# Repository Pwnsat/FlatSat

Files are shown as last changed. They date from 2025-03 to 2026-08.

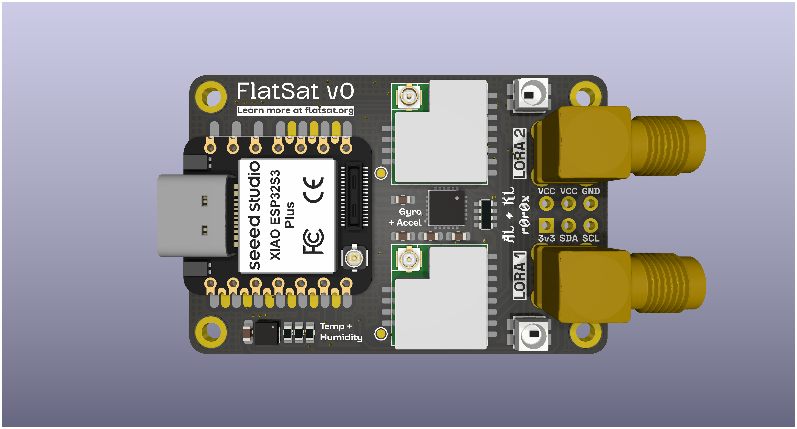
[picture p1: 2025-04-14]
assets/v0_FlatSat-Front.png

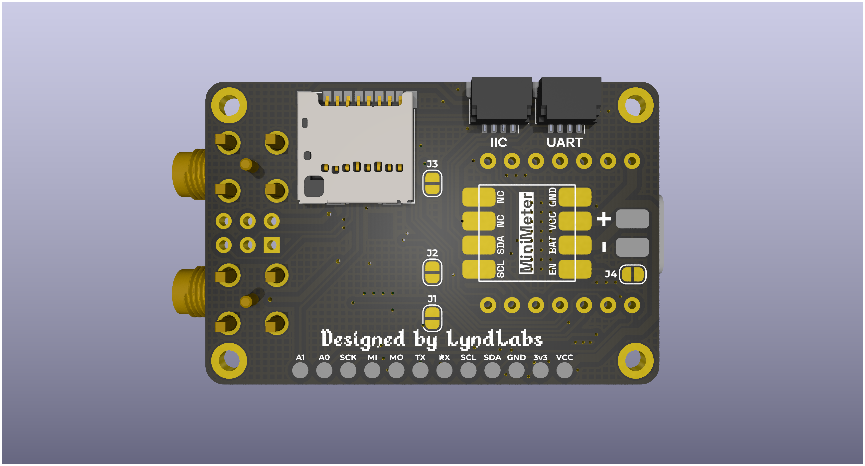
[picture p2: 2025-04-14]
assets/v0_FlatSat-Back.png

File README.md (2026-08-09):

<div align="center">

FlatSat Satellite Security Research Platform Banner

# FlatSat v1.0

**The world’s first open-source and hardware platform vulnerable-by-design, engineered specifically to learn space hacking adn aerospace cybersecurity.**

</div>

---

## Welcome to FlatSat

FlatSat is a hardware-based training platform designed to be vulnerable on purpose. It is built for hackers, engineers, and space enthusiasts who want to dive deep into space-grade systems, learn cybersecurity concepts, and prototype their own payloads in a safe, controlled environment.

The project simulates critical real-world satellite subsystems, orbital telemetry, and authentic aerospace communication protocols, serving as a bridge between hardware hacking and aerospace security research.

---

## What You Can Do With FlatSat

* **Hands-on Learning:** Use FlatSat as the hardware companion to your aerospace cybersecurity studies, featuring lessons on binary exploitation, secure communication, reverse engineering, and space protocols.
* **Hack Real Vulnerabilities:** Explore and exploit firmware designed to simulate historical or realistic software failures in orbiting infrastructure.
* **Join Space CTFs:** Participate in space-themed Capture The Flag challenges that simulate real satellite operation scenarios, turning your board into your own spacecraft.
* **Prototype Your Payloads:** Use the onboard components to develop and test your own payload logic, radio communication, or telemetry systems before deploying larger projects.

---

## Hardware Overview

FlatSat's physical architecture layout is fully accessible and designed for open hardware auditing:

* **On-Board Computer (OBC):** Powered by the dual-core Raspberry Pi RP2040 microcontroller.
* **Dual RF Link Subsystem:** Equipped with two independent Semtech SX1262 sub-GHz LoRa modules dedicated to Uplink (receive) and Downlink (transmit) configurations.
* **Onboard Sensors:** Features a BME280 environmental sensor and a LIS2DH12 3-axis accelerometer to emulate real spatial telemetry.
* **Exposed Auditing Interfaces:** Physical header connector breakouts for direct bus monitoring via UART, I2C, and SWD debug lines.

> **RF Compliance Note:** FlatSat operates exclusively within standard license-free ISM bands (typically 433 MHz or 915 MHz depending on your region). This ensures a legal, safe educational ecosystem that does not interfere with production space systems or critical ground infrastructure.

---

## Firmware & Attacks

* **[`Firmware/`](Firmware/):** The vulnerable-by-design firmware source, a pre-built `.uf2` ready to flash (`Firmware/build/`), and `platformio.ini` to build it yourself. See [`Firmware/README.md`](Firmware/README.md) for the full diff against the public baseline.
* **[`Attacks/`](Attacks/):** Eight attack scripts (`00`–`07`) exploiting the vulnerabilities above, each in an RF variant (HackRF/RTL-SDR) and a USB variant. See [`Attacks/README.md`](Attacks/README.md) for what's here, and the wiki (below) for the full step-by-step walkthrough of each one.

---

## Technical Documentation and Guides (Wiki)

All deep technical documentation, source analysis, and setup guides have been centralized. If you want to start compiling, debugging, or exploiting the platform, please visit the [FlatSat Wiki](https://github.com/Pwnsat/FlatSat/wiki):

* **[01. Quick Start Guide](https://github.com/Pwnsat/FlatSat/wiki/Getting-Started):** Toolchain setup, compiling the firmware, flashing the RP2040, and verifying hardware operations.
* **[02. Hardware Anatomy](https://github.com/Pwnsat/FlatSat/wiki/Hardware-Anatomy-&-Specifications):** Physical layout, schematics, pinouts, and hardware debugging ports.
* **[03. Core Firmware Architecture](https://github.com/Pwnsat/FlatSat/wiki/Firmware-&-System-Architecture):** Deep dive into the Asymmetric Multiprocessing (AMP) architecture dividing tasks across Core 0 and Core 1.
* **[04. Space Packet Protocol (CCSDS)](https://github.com/Pwnsat/FlatSat/wiki/Space-Packet-Protocol---CCSDS):** Aerospace framing standards, packet encapsulation structure, and the active APID registry.
* **[05. Offensive Attack Vectors](https://github.com/Pwnsat/FlatSat/wiki/Satellite-Hacking-&-Attack-Vectors):** The security playground. Explaining packet fuzzing, telecommand spoofing, buffer overflows, and unauthorized subsystem manipulation.
* **[06. Attack Walkthroughs (00–07)](https://github.com/Pwnsat/FlatSat/wiki/Attack-Walkthroughs-00-07):** Step-by-step: prerequisites, the exact command, and how to confirm each of the 8 validated attacks worked against real hardware.

---

## Collaboration and Community

This project is an open-source initiative maintained by PWNSAT and Electronic Cats. Contributions are highly welcome.

## Disclaimer

This project was created for educational purposes, to teach and learn aerospace cybersecurity. Neither PWNSAT nor Electronic Cats are responsible for how the knowledge, code, or tools hosted in this repository are used. Use only against hardware, firmware, or signal sources you own or are explicitly authorized to test.

## License

Electronic Cats invests time and resources providing this open source design, please support Electronic Cats and open-source hardware by purchasing products from Electronic Cats!

Designed by PWNSAT and Electronic Cats.

Hardware released under an CERN Open Hardware Licence v1.2. See the LICENSE_HARDWARE file for more information. Firmware and attack scripts are released under GPL-2.0-or-later — see LICENSE_FIRMWARE and Attacks/LICENSE.

PWNSAT and Electronic Cats are a registered trademark, please do not use if you sell these PCBs.

# Special Thanks
A special thanks to **Alex Lynd**. His support made it possible to kick off the first version of the project, and his contribution remains a fundamental part of PWNSAT. His work will always be embedded in what this project has become.

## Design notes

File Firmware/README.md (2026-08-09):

# Changes vs. the public firmware

**Current version: v1.0.3.** The public v1.0.0 baseline this README diffs
against (previously at the now-retired `Pwnsat/FlatSat_Firmware` repo,
commit `f94aa87`, "FlatSat Firmware v1.0.0 Public") is preserved as a
[legacy v1.0.0 release](https://github.com/Pwnsat/FlatSat/releases/tag/v1.0.0)
on this repo — binary only, since merging its source files alongside this
folder's would just create two conflicting copies of the same file names.

This README documents everything v1.0.3 adds or changes relative to that
v1.0.0 baseline, generated by a direct file-by-file `diff` between both
source trees, not from memory.

## Changelog highlights (v1.0.0 → v1.0.3)

* **New:** ground-station authentication, mission modes, downlink
  encryption (AES-128), GPS navigation, a simulated SpaceCAN bus console,
  a "secured" SPP packet variant, 4 new APIDs — see **New features**
  below for the full breakdown.
* **Fixed:** LoRa radios failing to initialize (missing `tcxoVoltage=0.0`),
  a downlink transmit race, debug-mode payload corruption, 32 misaligned
  serial log lines — see **Bugs fixed** below.
* Every new subsystem above ships with at least one intentional
  vulnerability, backing the [8 attack scripts](../Attacks/) and the
  wiki's [Attack Walkthroughs](https://github.com/Pwnsat/FlatSat/wiki/Attack-Walkthroughs-00-07).

## Summary

The public firmware is a functional baseline: two SX1262 LoRa radios,
CCSDS/SPP protocol, sensors (IMU, BME280), dual-core USB serial console.
This firmware builds on that base and adds **a full layer of simulated
real-satellite-mission subsystems** (ground-station authentication, mission
modes, downlink encryption, a simulated CAN bus, GPS navigation) — with
intentional vulnerabilities, which are what the attack scripts under
[`../Attacks/`](../Attacks/) exploit.

## How to build

**Board:** Raspberry Pi Pico / RP2040 (`#include "hardware/watchdog.h"` is a
Pico SDK header; the sketch uses the RP2040 core from
[earlephilhower](https://github.com/earlephilhower/arduino-pico), which
ships native USB support via `Adafruit_TinyUSB` for this firmware's dual-USB
core).

**Third-party libraries** (Arduino Library Manager, or the PlatformIO
equivalent):

| Library | Used for |
|---|---|
| `RadioLib` | SX1262 LoRa radios (uplink/downlink) |
| `Adafruit_BME280` (pulls in `Adafruit_Sensor` as a transitive dependency) | Environmental sensor |
| `SparkFun_LIS2DH12` | Accelerometer |
| `NeoPixelBus` | Status LED |
| `Adafruit_TinyUSB` (bundled with earlephilhower's RP2040 core, no separate install needed) | Dual-core USB serial console (CDC) |

This folder includes `platformio.ini` (`pico_tinyusb` environment) with all
4 `lib_deps` pinned — `pio run` from here builds with no manual steps. If
you use the Arduino IDE instead, install the earlephilhower RP2040 core via
Boards Manager and the libraries in the table above via Library Manager
before opening `firmware.ino`.

## Pre-built binary

`build/flatsat-firmware.uf2` is a build of this exact source, generated
with the `platformio.ini` above (`pio run`, `pico_tinyusb` environment) —
RAM 8.4% (22016/262144 bytes), Flash 7.8% (163756/2093056 bytes). To flash:
hold the Pico's BOOTSEL button while plugging it in over USB (it enumerates
as a mass-storage volume), then copy the `.uf2` onto it — the Pico reboots
on its own into the new firmware. **Not verified on real hardware:** this
specific binary hasn't been flashed or tested on physical FlatSat hardware
— it's a clean recompile of the source to have a ready artifact, not
necessarily the exact binary that ran during development/testing. The
source code is identical either way; if you need the "ran on real
hardware" guarantee, flash and test this `.uf2` yourself before relying on
it for a live demo.

## New files (don't exist in the public firmware)

| File | What it does |
|---|---|
| `secure_link.cpp` / `.h` | Encrypts/decrypts the downlink payload with AES-128. A static 16-byte key embedded in the binary, ECB mode, no IV — the documented vulnerability. Exposes `secureLinkIsEnabled()`, `secureLinkEncodePayload()`, `secureLinkDecodePayload()`. |
| `spacecan.cpp` / `.h` | Simulated SpaceCAN bus console (serial port, text), with 3 nodes (`SENSOR`/`MOTOR`/`BATTERY`), fragmented-frame reassembly, frame injection with no origin check (`SC INJECT`), and manual node reset (`SC RESET`) — 3 intentional vulnerabilities documented in the file's own header. Also contains the PWNSAT console shell (banner, menu, sensor dashboard mode) — none of this touches the radio/USB command path. |

## Bugs fixed vs. the public firmware

1. **LoRa radios wouldn't initialize (-707 /
   `RADIOLIB_ERR_SPI_CMD_FAILED`) — root cause found and fixed.** The
   public firmware calls `radio0.begin()` / `radio1.begin()` with no
   arguments, which leaves `tcxoVoltage` at RadioLib's default (1.6V) —
   telling the chip to expect a TCXO this module doesn't have (it uses a
   plain XTAL), so internal calibration never completes. Fixed in
   `ruplink.cpp` / `rdownlink.cpp`: explicit `tcxoVoltage=0.0`.
2. **`downlinkRadioTransmit()` (blocking) could fail if a previous
   transmission hadn't finished.** Added `radio1.finishTransmit()` +
   `delay(100)` before transmitting.
3. **`uplinkRadioCheckPacketReceived()` corrupted the received payload in
   debug mode.** The public firmware does a hex-string → bytes → callback
   roundtrip that lost data; raw bytes (`byteArr`) are now passed straight
   to the callback instead.
4. **Misaligned Serial logs.** Several `Serial.printf(...)` calls in
   `ruplink.cpp`/`rdownlink.cpp`/`worker.cpp` ended in `\n` instead of
   `\r\n` — many serial terminals don't return to column 0 without the
   explicit `\r`. 32 occurrences fixed.

## New features

### Ground Station (GS) authentication and access control
A full subsystem in `worker.cpp`: GS modes (`GS_MODE`), access
challenge/response (`GS_ACCESS`), status (`GS_STATUS`). The access "gate"
requires the GPS to report a position within a 35km radius
(`gs_station_radius_m`) of a fixed GS coordinate
(`gs_station_lat_e7`/`gs_station_lon_e7`). The challenge/response uses a
hardcoded shared key (`gs_shared_auth_key = 0xC0DEFACE`) XORed against the
challenge — an intentional vulnerability, exploited by the `05_gs_auth_spoofing`
attack script.

### GPS navigation
`sensors.cpp`/`.h`: a full NMEA parser (GGA/RMC sentences), a new dedicated
UART (`PIN_GPS_TX`/`PIN_GPS_RX`, pins 0/1), a `gps_nav_t` struct with
fix/lat/lon/alt/satellite-count/UTC date-time. A new `GET_NAV` APID
(`0x0E`) exposes a navigation snapshot over telemetry.

### Mission modes
`SAFE` / `NOMINAL` / `PAYLOAD` / `SCIENCE` / `CONTINGENCY` (`mission.h`),
controllable via the new `SET_MISSION_MODE` APID (`0x0D`), with status
flags (`MISSION_FLAG_*`) reporting subsystem health (BME/ACC/GPS/secure
link/payload armed/USB debug active).

### Downlink encryption (secure link)
AES-128 active by default on the downlink payload (`secure_link.cpp`).
Toggled via the `AES_CONFIG` APID (`0x0A`). Static key, no rotation, no IV
— documented as a vulnerability, not an oversight.

### "Secured" SPP packet format (parallel, doesn't replace the existing one)
`spp.cpp`/`.h`: new `spp_tc_build_packet_secured()` /
`spp_tm_build_packet_secured()` functions that prepend a 4-byte secondary
header (a plain monotonic counter, **not cryptographic** — no IV, no
timestamp, no freshness validation) before the payload, setting the
`SecHdr` flag. Doesn't touch any of the 20+ existing callers of
`spp_build_packet()`.

### Other new APIDs
`FLASH_READ` (`0x0B`, reads up to 32 bytes from a fixed blob behind a
hardcoded "unlock tag" `0xC35A` — a flash-read vulnerability with no real
authentication), `GET_STATUS` (`0x0C`), `GET_PAYLOAD_STATUS` (`0x0F`),
`DEBUG_CONFIG` (`0x10`, enables debug commands over USB only).

### Command source separation (radio vs. USB)
The public firmware had a single `commandHandler()`. There are now
`commandHandlerRadio()` / `commandHandlerUSB()`, both reaching
`commandHandlerInternal(..., command_source_t source)` — this lets certain
commands (debug, some GS commands) be restricted to a specific origin
(`groundStationCommandAllowed()`, `source == COMMAND_SOURCE_USB` checks).

### Serial-console telemetry dashboard
`printSystemStatusDashboard()` / `telemetryDashboardWorker()` — an
interactive text mode that shows live sensor/GPS/GS/mission state,
launched from the PWNSAT console (`spacecan.cpp`), without affecting the
radio loop.

## Cross-reference with the vulnerability catalog

This firmware is the base the [`../Attacks/`](../Attacks/) scripts (00–07)
are built against, and covers 11 findings from the internal vulnerability
catalog (#4, #5, #10, #12, #13, #14, #15, #16, #17, #21, #22). See
[`../Attacks/README.md`](../Attacks/README.md) and the wiki for the
per-attack detail.

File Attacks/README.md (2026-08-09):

# FlatSat Attacks 00–07

Eight attack scripts exploiting the vulnerabilities documented in
[`../Firmware/`](../Firmware/), each available in two variants:

- **`*_rf.py`** — the physically-realistic version, over the air via
  HackRF (uplink) and RTL-SDR/CatSniffer (downlink). Confirmed on real
  hardware.
- **`*_usb.py`** — the same finding, delivered over FlatSat's USB serial
  link instead of RF. Useful to rehearse the effect without an SDR.

| Folder | Attack | APID(s) |
| --- | --- | --- |
| `00_recon_apid_enum/` | Unauthenticated black-box APID enumeration | various |
| `01_eavesdropping/` | Passive downlink decryption (static AES-128 key) | `SEND_TM` |
| `02_fuzzing_crash/` | `BROADCAST_MSG` integer underflow crash | `0x06` |
| `03_command_injection/` | Unauthenticated `SET_THRUSTER` | `0x04` |
| `04_gps_spoofing/` | Real GPS L1 spoofing + a debug GPS-override demo | — |
| `05_gs_auth_spoofing/` | Ground-station auth bypass (static XOR key) | `0x12` |
| `06_replay/` | Telecommand replay (no anti-replay) | `0x01` |
| `07_resetc/` | Unauthenticated `RESETC` reboot | `0x02` |

Full step-by-step walkthrough for each attack — prerequisites, exact
commands, and how to confirm it worked — is in the wiki:
**[Attack Walkthroughs (00–07)](https://github.com/Pwnsat/FlatSat/wiki/Attack-Walkthroughs-00-07)**.
This README only lists what's here; it isn't a substitute for that page.

## Dependency: PWNSAT-C3

None of these scripts vendor their own SPP/CCSDS codec or AES
implementation — `lib/pwnsat_packets.py` and `lib/flatsat_usb.py` import
`pwnsat_tools/` from **[PWNSAT-C3](https://github.com/Pwnsat/PWNSAT-C3)**,
the ground-station dashboard repo. Clone both repos as siblings under the
same parent directory:

```shell
git clone https://github.com/Pwnsat/FlatSat
git clone https://github.com/Pwnsat/PWNSAT-C3
```

```
some-parent-dir/
├── FlatSat/
│   └── Attacks/   <- you are here
└── PWNSAT-C3/
    └── pwnsat_tools/
```

No other install step is needed beyond what
[PWNSAT-C3's own INSTALL.md](https://github.com/Pwnsat/PWNSAT-C3/wiki/Getting-Started)
already covers (Python deps, and the optional GNU Radio/SoapySDR/HackRF
toolchain the `_rf.py` scripts need).

## `lib/`

Shared code the scripts above import, not run directly:

| File | Purpose |
| --- | --- |
| `pwnsat_packets.py` | Bootstraps `pwnsat_tools/` onto `sys.path` and re-exports packet building/decoding. |
| `flatsat_usb.py` | `FlatSatUSB` — the USB serial transport the `*_usb.py` scripts use. |
| `pwnsat_lora_tx.py` | HackRF TX helper (shells out to `hackrf_transfer`). |
| `pwnsat_lora_rx_capture.py` | GNU Radio LoRa RX capture helper. |
| `pwnsat_catsniffer_rx.py` | CatSniffer-based dedicated downlink listener (two-radio setup). |
| `pwnsat_rtlsdr_rx.py` | RTL-SDR downlink listener, reuses `01_eavesdropping/pwnsat_lora_rx.py`. |
| `decrypt_display.py` | Decrypts and pretty-prints a captured downlink payload. |
| `require_gnuradio.py` | Fails fast with a clear message if GNU Radio isn't importable. |

## Safety

Every script here transmits over RF or sends real commands. Only run these
against a FlatSat board, lab transmitter, or signal source you own or are
explicitly authorized to test.

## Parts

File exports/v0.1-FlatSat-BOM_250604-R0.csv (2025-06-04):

Designator | Value | Footprint | Datasheet | LCSC | Qty
C1,C3,C4,C5,C6 | 100nF | 603 | ~ | C14663 | 5
C2 | 2.2uf | 603 | ~ | C57895 | 1
D1,D2 | SK6812MINI | 3535 |  | C2922787 | 2
J2,J3 | JST SH | SM04B | ~ | C160404 | 2
J7 | MicroSD |  | https://www.molex.com/en-us/products/part-detail/1040310811 | C585350 | 1
R4,R5 | 4.7K | 603 | ~ | C99782 | 2
RN1 | 10K | Resistor_SMD:R_Array_Convex_4x0603 | ~ | C110924 | 1
U2 | MPU-6500 | Sensor_Motion:InvenSense_QFN-24_4x4mm_P0.5mm | https://invensense.tdk.com/wp-content/uploads/2015/02/MPU-6000-Datasheet1.pdf | C50278 | 1
U3 | BME280 | Package_LGA:Bosch_LGA-8_2.5x2.5mm_P0.65mm_ClockwisePinNumbering | https://www.bosch-sensortec.com/media/boschsensortec/downloads/datasheets/bst-bme280-ds002.pdf | C92489 | 1
U5,U6 | WIO-SX1262 |  | https://www.seeedstudio.com/Wio-SX1262-Wireless-Module-p-5981.html | NA | 2

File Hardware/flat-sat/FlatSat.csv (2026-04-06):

Reference | Value | Footprint | Qty | LCSC# | Mouser# | manf# | DNP
BOOT1,Button1,Button2,RESET1 | SW | FlatSat:TS1088R02026 | 4 | C455281
C1,C5,C7,C8,C13,C14,C18,C19,C24,C25,C27,C28,C32,C33,C34,C35,C36,C37,C38 | 0.1uF | Capacitor_SMD:C_0402_1005Metric | 19 | C56392
C2,C15 | 100pF | Capacitor_SMD:C_0402_1005Metric | 2 | C541374
C3,C4,C16,C17 | 3.3pF | Capacitor_SMD:C_0402_1005Metric | 4 | C1565
C6,C26,C31 | 1uF | Capacitor_SMD:C_0402_1005Metric | 3 | C52923
C9,C20 | 47pF | Capacitor_SMD:C_0402_1005Metric | 2 | C437519
C10,C12,C21,C23 | 1nF | Capacitor_SMD:C_0402_1005Metric | 4 | C335530
C11,C22 | 470nF | Capacitor_SMD:C_0402_1005Metric | 2 | C47339
C29,C30 | 27pF | Capacitor_SMD:C_0402_1005Metric | 2 | C424826 | 81-GJM1555C1H270FB1D
D2 | SK6812MINI | Library:SK6812MINI-HS | 1 | C2922787
F1 | 0.75A | Fuse:Fuse_0603_1608Metric_Pad1.05x0.95mm_HandSolder | 1 | C182438 | 594-MFU0805FF00500P1
J1,J2 | Antenna | FlatSat:SMA_EDGE | 2 | C530661
J3 | periphs | Connector_PinHeader_2.54mm:PinHeader_1x06_P2.54mm_Vertical | 1
J4 | SWD | Connector_PinHeader_2.54mm:PinHeader_1x04_P2.54mm_Vertical | 1 |  |  |  | DNP
JP1,JP2 | Jumper | Jumper:SolderJumper-3_P1.3mm_Bridged12_RoundedPad1.0x1.5mm_NumberLabels | 2 |  |  |  | DNP
L1,L4 | 9.1nH | Inductor_SMD:L_0603_1608Metric | 2 | C395094
L2,L5 | 47nH | Inductor_SMD:L_0603_1608Metric | 2 | C578001
L3,L6 | 15uH | Inductor_SMD:L_0603_1608Metric | 2 | C57838
P1 | USB_C_Plug_USB2.0 | FlatSat:C393939 | 1 | C709357
R1,R2 | 5k1 | Resistor_SMD:R_0402_1005Metric | 2 | C25905
R3,R4,R6,R7 | 100R | Resistor_SMD:R_0402_1005Metric | 4 | C25076
R5 | 10k | Resistor_SMD:R_0402_1005Metric | 1 | C25531 | 594-MCS04020D1002BE0
R8,R10 | 27 | Resistor_SMD:R_0402_1005Metric | 2 | C25100 | 755-ESR01MZPF27R0
R9,R15 | 4.7k | Resistor_SMD:R_0402_1005Metric | 2 | C25900 | 594-MCS04020D1002BE0
R13 | 1k | Resistor_SMD:R_0402_1005Metric | 1 | C11702 | 594-MCS0402MD1001DE0
R14 | 470 | Resistor_SMD:R_0402_1005Metric | 1 | C25117
U1 | TLV75733PDBVR | Package_TO_SOT_SMD:SOT-23-5 | 1 | C485517
U2,U6 | 0900FM15D0039 | FlatSat:0900FM15D0039E | 2 |  | 609-0900FM15D0039E | 0900FM15D0039E
U3,U7 | PE42421 | Package_TO_SOT_SMD:SOT-363_SC-70-6 | 2 | C470893 | 81-PE42421SCAA-Z | PE42421SCAA-Z
U4,U8 | SX1262IMLTRT | Package_DFN_QFN:QFN-24-1EP_4x4mm_P0.5mm_EP2.65x2.65mm | 2 | C191341 | 947-SX1262IMLTRT | SX1262IMLTRT
U5 | IS25LP032D-JTLE-TR | Package_SON:Winbond_USON-8-2EP_3x4mm_P0.8mm_EP0.2x0.8mm | 1 | C5119926 |  | IS25LP032D-JTLE-TR
U9 | RP2040 | Package_DFN_QFN:QFN-56-1EP_7x7mm_P0.4mm_EP3.2x3.2mm | 1 | C2040 |  | RP2040
U10 | LIS2DH | Package_LGA:LGA-14_2x2mm_P0.35mm_LayoutBorder3x4y | 1 | C155670
U11 | BME280 /BMP280 | Package_LGA:Bosch_LGA-8_2.5x2.5mm_P0.65mm_ClockwisePinNumbering | 1 | C92489
Y1,Y2 | 32Mhz | Crystal:Crystal_SMD_2520-4Pin_2.5x2.0mm | 2 | C255969 |  | Q24FA20H0021700
Y3 | 12MHz | Crystal:Crystal_SMD_3225-4Pin_3.2x2.5mm | 1 | C2848217 |  | XC32M4-12.000-F20NJDT

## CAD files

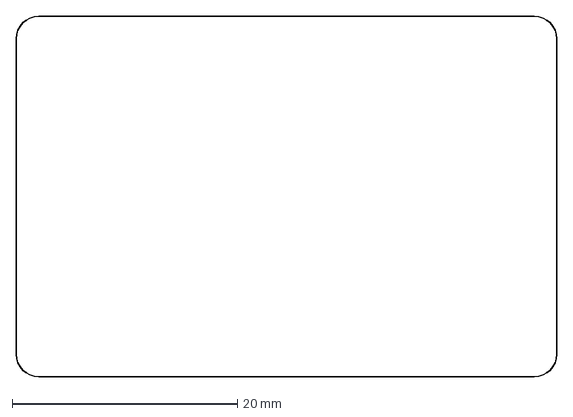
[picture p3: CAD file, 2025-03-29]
assets/outline.dxf
48.0 x 32.0 mm

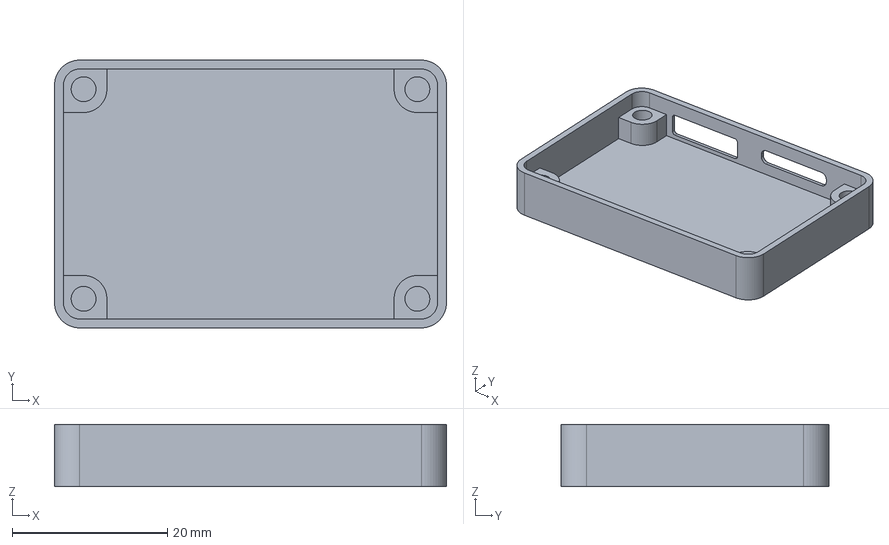
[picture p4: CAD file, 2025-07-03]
exports/v0-FlatSat-Enclosure.step
50.5 x 34.5 x 8.00 mm

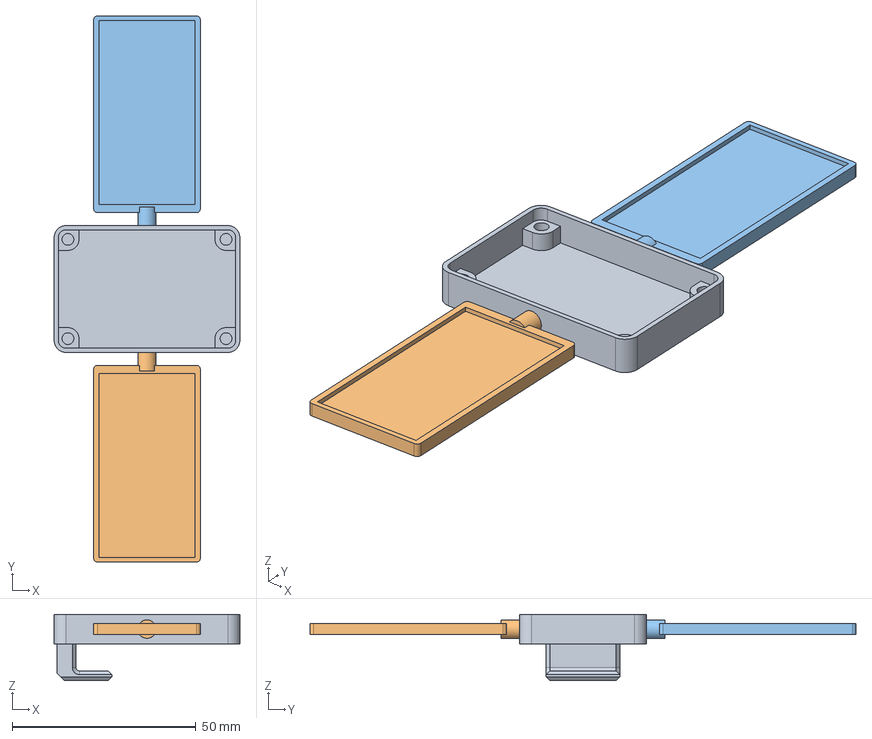
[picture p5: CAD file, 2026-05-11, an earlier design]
Hardware/Legacy/v0-FlatSat-Sat_MOunt.FCStd
50.5 x 148.5 x 18.0 mm
SolarPanel2
SolarPanel1

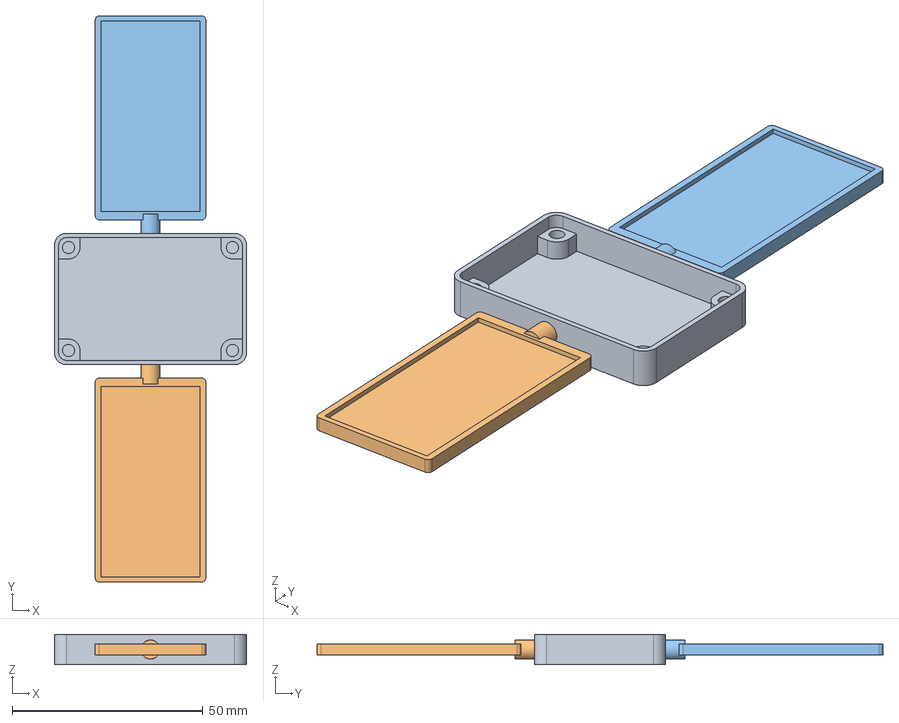
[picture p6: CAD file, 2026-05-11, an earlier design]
Hardware/Legacy/v0-FlatSat-Sat.FCStd
50.5 x 148.5 x 8.00 mm
SolarPanel2
SolarPanel1

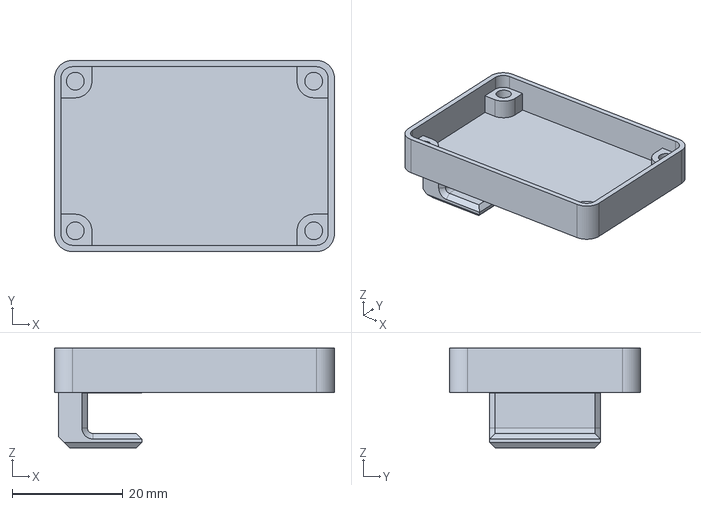
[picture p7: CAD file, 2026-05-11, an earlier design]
Hardware/Legacy/v0-FlatSat-Mount.FCStd
50.5 x 34.5 x 18.0 mm

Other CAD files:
src/v0-FlatSat-Enclosure.FCStd
Hardware/Legacy/v0-FlatSat-Outline.FCStd
Hardware/Legacy/v0-FlatSat-Sat-SolarPanel.step
Hardware/Legacy/v0-FlatSat-Enclosure-Body_STL.stl
Hardware/Legacy/v0-FlatSat-Enclosure.FCStd
Hardware/Legacy/v0-FlatSat-Sat-Mount.stl
Hardware/Legacy/v0-FlatSat-Sat-SolarPanel.stl

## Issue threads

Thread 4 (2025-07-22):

v1.0 - RFM95

JahazielLem, 2025-07-22:
- Make board easily compatible with RFM95 as new version radio

JahazielLem, 2025-07-22:
Or LR1121, maybe a modern o more complex version
https://www.seeedstudio.com/Wio-LR1121-with-IPEX-antenna-connector-p-6479.html

AlexLynd, 2025-07-24:
Working on it now!  Just need to route the traces...

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

AlexLynd, 2025-07-26:
How many more pins do we need?  On the last version, we had 2 unused pins - and I think we'll have the same on this one.  And also, do we intend to sell this as a "workshop edition" or just for presenters?  I can definitely get us a discount / sponsored parts!

JahazielLem, 2025-07-29:
With the two free is enough, with the LR1121 is only for presenters but with the sx1262 or RFM is for sell, so here we can look for sponsorship o collabs

AlexLynd, 2025-08-05:
Got it!  Also should I also get rid of microsd detection pin?  I feel like we can just detect it in software... and there's not really a reason to have detection tied to an interrupt

AlexLynd, 2025-08-05:
@JahazielLem also you want `DIO9` connected on just one of them?  what about the busy pins
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

JahazielLem, 2025-08-06:
@AlexLynd  I will bought a module, in the next week will arrive, so let me test what's the better configuration for the pins, maybe the board with this module will have only one LR11 and a RFM as the second radio

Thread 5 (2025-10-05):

Inquiry about purchasing FlatSat kit

hadi1123, 2025-10-05:
Hello! 👋
I came across your FlatSat project and I’m really interested in purchasing one for educational and research purposes. However, I couldn’t find a purchasing link or store page in the repository.

Could you please share details about how or where I can buy the FlatSat kit (or any recommended distributor)?

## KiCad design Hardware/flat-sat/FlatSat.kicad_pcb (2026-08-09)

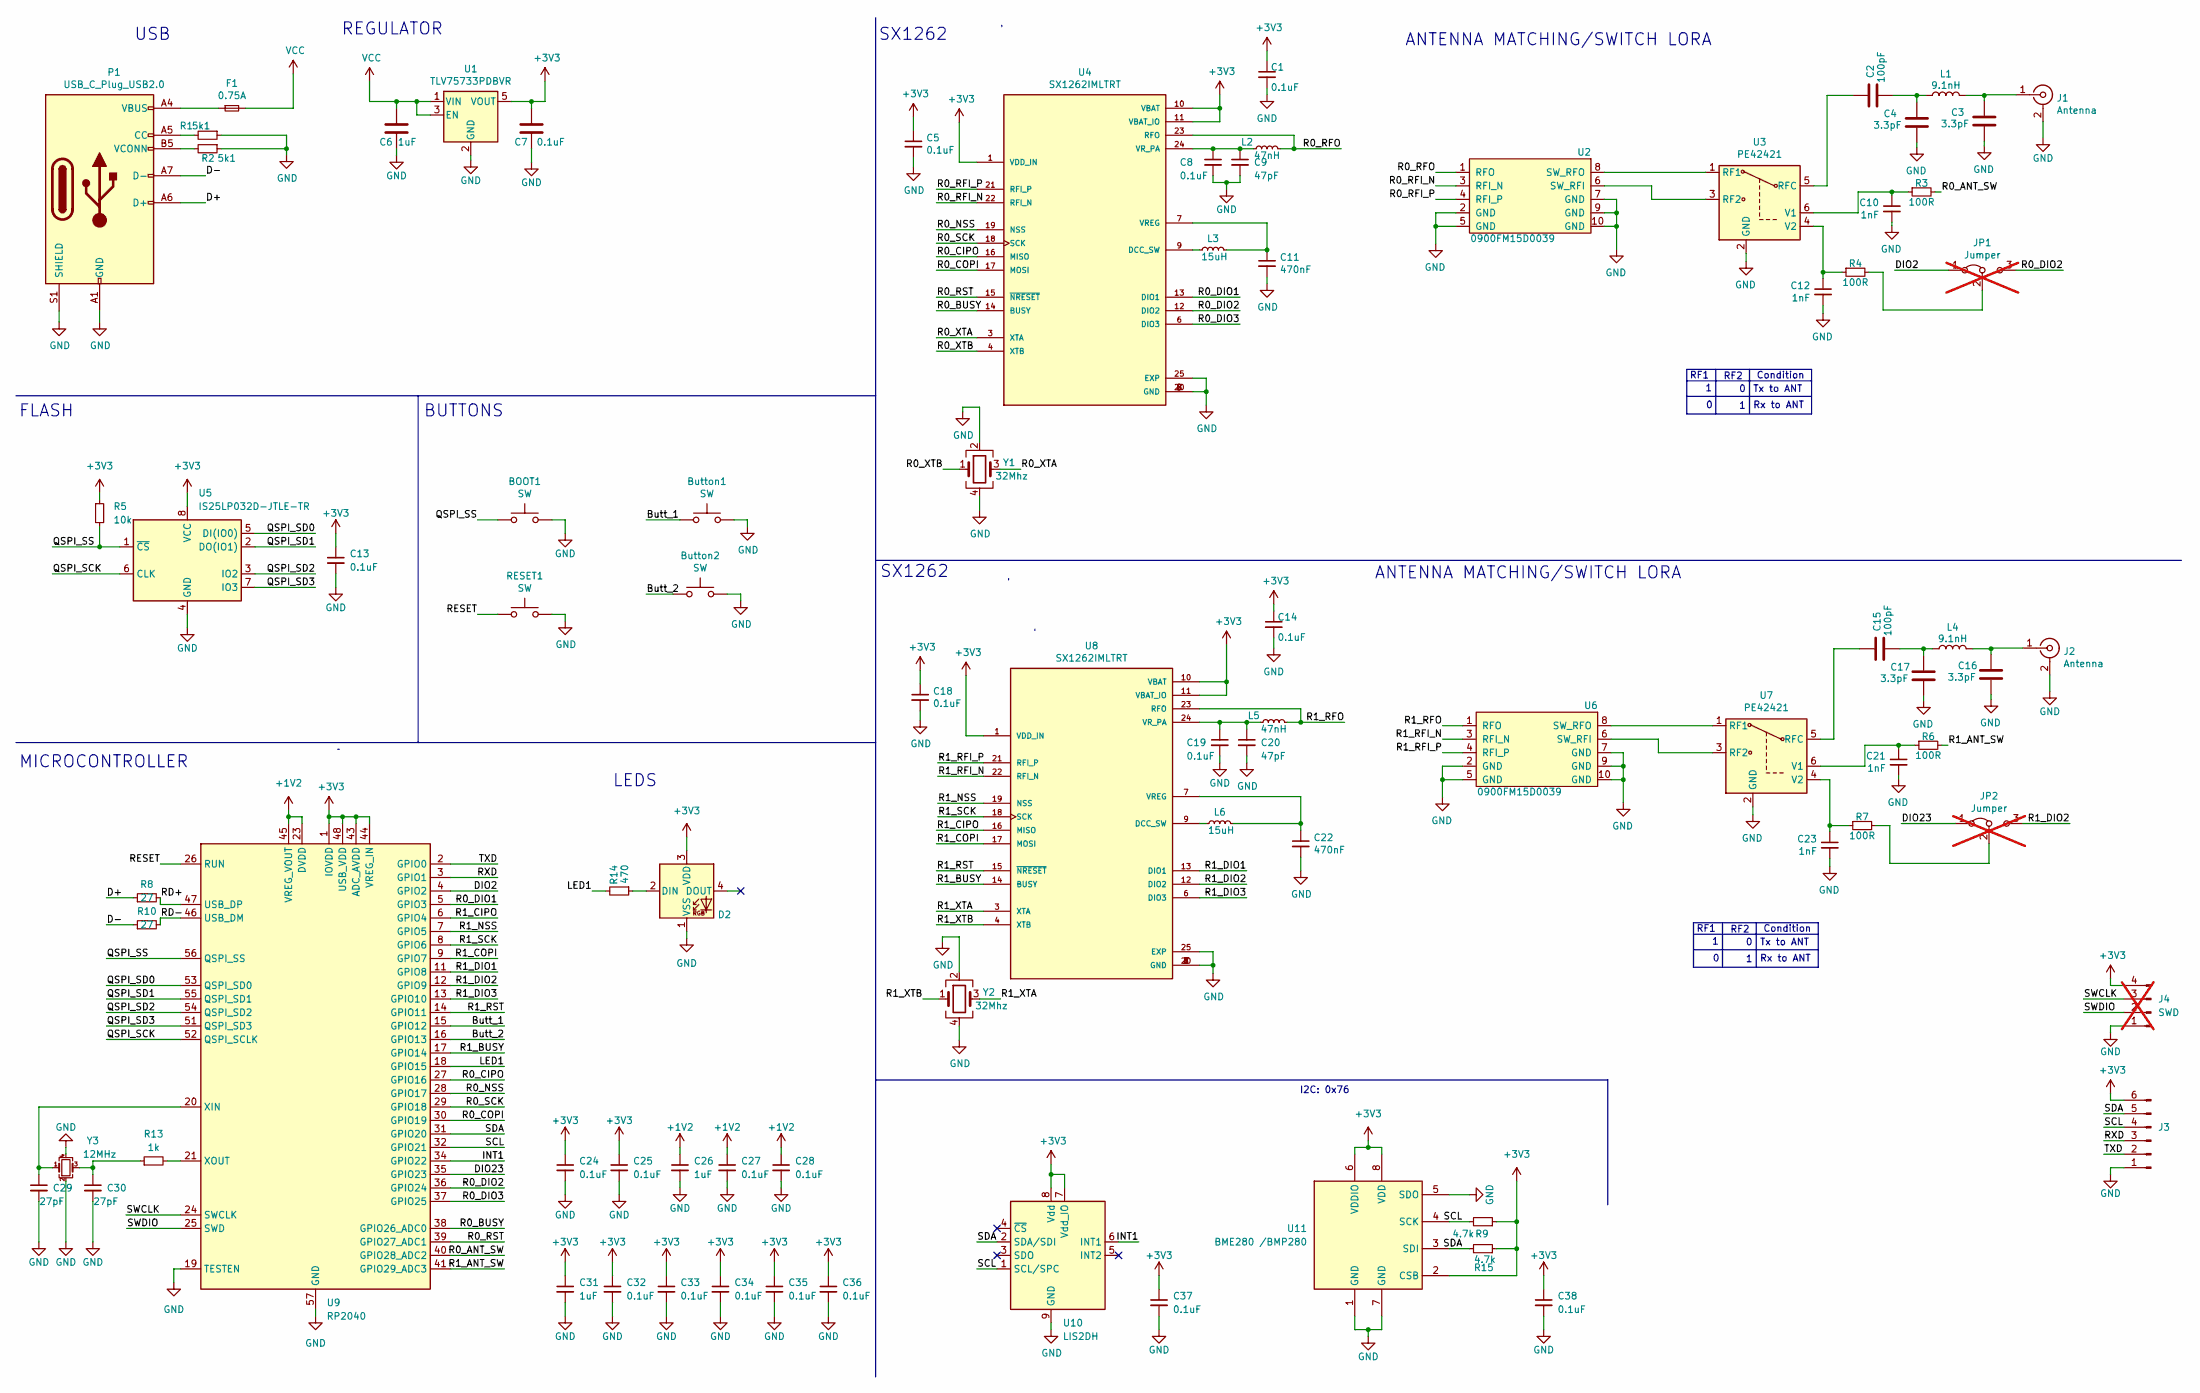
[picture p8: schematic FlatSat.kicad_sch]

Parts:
BOOT1: SW; TS1088R02026; LCSC# C455281
Button1, Button2: SW; TS1088R02026; LCSC# C455281
C1, C5, C7, C8, C13, C14, C18, C19, C24, C25, C27, C28, C32, C33, C34, C35, C36, C37, C38: 0.1uF; C_0402_1005Metric; LCSC# C56392
C2, C15: 100pF; C_0402_1005Metric; LCSC# C541374
C3, C4, C16, C17: 3.3pF; C_0402_1005Metric; LCSC# C1565
C6, C26, C31: 1uF; C_0402_1005Metric; LCSC# C52923
C9, C20: 47pF; C_0402_1005Metric; LCSC# C437519
C10, C12, C21, C23: 1nF; C_0402_1005Metric; LCSC# C335530
C11, C22: 470nF; C_0402_1005Metric; LCSC# C47339
C29, C30: 27pF; C_0402_1005Metric; Mouser# 81-GJM1555C1H270FB1D; LCSC# C424826
D2: SK6812MINI; SK6812MINI-HS; LCSC# C2922787
F1: 0.75A; Fuse_0603_1608Metric_Pad1.05x0.95mm_HandSolder; Mouser# 594-MFU0805FF00500P1
J1, J2: Antenna; SMA_EDGE; LCSC# C530661
J3: periphs; PinHeader_1x06_P2.54mm_Vertical
J4: SWD; PinHeader_1x04_P2.54mm_Vertical; not fitted
JP1, JP2: Jumper; SolderJumper-3_P1.3mm_Bridged12_RoundedPad1.0x1.5mm_NumberL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; not fitted
L1, L4: 9.1nH; L_0603_1608Metric; LCSC# C395094
L2, L5: 47nH; L_0603_1608Metric; LCSC# C578001
L3, L6: 15uH; L_0603_1608Metric; LCSC# C57838
P1: USB_C_Plug_USB2.0; C393939; LCSC# C709357
R1, R2: 5k1; R_0402_1005Metric; LCSC# C25905
R3, R4, R6, R7: 100R; R_0402_1005Metric; LCSC# C25076
R5: 10k; R_0402_1005Metric; Mouser# 594-MCS04020D1002BE0; LCSC# C25531
R8, R10: 27; R_0402_1005Metric; Mouser# 755-ESR01MZPF27R0; LCSC# C25100
R9, R15: 4.7k; R_0402_1005Metric; Mouser# 594-MCS04020D1002BE0; LCSC# C25900
R13: 1k; R_0402_1005Metric; Mouser# 594-MCS0402MD1001DE0; LCSC# C11702
R14: 470; R_0402_1005Metric; LCSC# C25117
RESET1: SW; TS1088R02026; LCSC# C455281
U1: TLV75733PDBVR; SOT-23-5; LCSC# C485517
U2, U6: 0900FM15D0039; 0900FM15D0039E; Mouser# 609-0900FM15D0039E
U3, U7: PE42421; SOT-363_SC-70-6; Mouser# 81-PE42421SCAA-Z; LCSC# C470893
U4, U8: SX1262IMLTRT; QFN-24-1EP_4x4mm_P0.5mm_EP2.65x2.65mm; Mouser# 947-SX1262IMLTRT
U5: IS25LP032D-JTLE-TR; Winbond_USON-8-2EP_3x4mm_P0.8mm_EP0.2x0.8mm; LCSC# C5119926
U9: RP2040; QFN-56-1EP_7x7mm_P0.4mm_EP3.2x3.2mm; LCSC# C2040
U10: LIS2DH; LGA-14_2x2mm_P0.35mm_LayoutBorder3x4y; LCSC# C155670
U11: BME280 /BMP280; Bosch_LGA-8_2.5x2.5mm_P0.65mm_ClockwisePinNumbering; LCSC# C92489
Y1, Y2: 32Mhz; Crystal_SMD_2520-4Pin_2.5x2.0mm; LCSC# C255969
Y3: 12MHz; Crystal_SMD_3225-4Pin_3.2x2.5mm; LCSC# C2848217

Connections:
+1V2: C26.1, C27.1, C28.1, U9.23 (DVDD), U9.45 (VREG_VOUT), U9.50 (DVDD)
+3V3: C1.1, C5.1, C7.2, C13.1, C14.1, C18.1, C24.1, C25.1, C31.1, C32.1, C33.1, C34.1, C35.1, C36.1, C37.1, C38.1, D2.3 (VDD), J3.6, J4.4, R5.1, R9.1, R15.1, U1.5 (VOUT), U4.1 (VDD_IN), U4.10 (VBAT), U4.11 (VBAT_IO), U5.8 (VCC), U8.1 (VDD_IN), U8.10 (VBAT), U8.11 (VBAT_IO), U9.1 (IOVDD), U9.10 (IOVDD), U9.22 (IOVDD), U9.33 (IOVDD), U9.42 (IOVDD), U9.43 (ADC_AVDD), U9.44 (VREG_IN), U9.48 (USB_VDD), U9.49 (IOVDD), U10.7 (Vdd_IO), U10.8 (Vdd), U11.2 (CSB), U11.6 (VDDIO), U11.8 (VDD)
/Butt_1: Button1.1, U9.15 (GPIO12)
/Butt_2: Button2.1, U9.16 (GPIO13)
/D+: P1.A6 (D+), R8.1
/D-: P1.A7 (D-), R10.1
/DIO2: JP1.1 (A), U9.4 (GPIO2)
/DIO23: JP2.1 (A), U9.35 (GPIO23)
/INT1: U9.34 (GPIO22), U10.6 (INT1)
/LED1: R14.2, U9.18 (GPIO15)
/QSPI_SCK: U5.6 (CLK), U9.52 (QSPI_SCLK)
/QSPI_SD0: U5.5 (DI(IO0)), U9.53 (QSPI_SD0)
/QSPI_SD1: U5.2 (DO(IO1)), U9.55 (QSPI_SD1)
/QSPI_SD2: U5.3 (IO2), U9.54 (QSPI_SD2)
/QSPI_SD3: U5.7 (IO3), U9.51 (QSPI_SD3)
/QSPI_SS: BOOT1.1, R5.2, U5.1 (~CS), U9.56 (QSPI_SS)
/R0_ANT_SW: R3.2, U9.40 (GPIO28_ADC2)
/R0_BUSY: U4.14 (BUSY), U9.38 (GPIO26_ADC0)
/R0_CIPO: U4.16 (MISO), U9.27 (GPIO16)
/R0_COPI: U4.17 (MOSI), U9.30 (GPIO19)
/R0_DIO1: U4.13 (DIO1), U9.5 (GPIO3)
/R0_DIO2: JP1.3 (B), U4.12 (DIO2), U9.36 (GPIO24)
/R0_DIO3: U4.6 (DIO3), U9.37 (GPIO25)
/R0_NSS: U4.19 (NSS), U9.28 (GPIO17)
/R0_RFI_N: U2.3 (RFI_N), U4.22 (RFI_N)
/R0_RFI_P: U2.4 (RFI_P), U4.21 (RFI_P)
/R0_RFO: L2.2, U2.1 (RFO), U4.23 (RFO)
/R0_RST: U4.15 (~NRESET), U9.39 (GPIO27_ADC1)
/R0_SCK: U4.18 (SCK), U9.29 (GPIO18)
/R0_XTA: U4.3 (XTA), Y1.3
/R0_XTB: U4.4 (XTB), Y1.1
/R1_ANT_SW: R6.2, U9.41 (GPIO29_ADC3)
/R1_BUSY: U8.14 (BUSY), U9.17 (GPIO14)
/R1_CIPO: U8.16 (MISO), U9.6 (GPIO4)
/R1_COPI: U8.17 (MOSI), U9.9 (GPIO7)
/R1_DIO1: U8.13 (DIO1), U9.11 (GPIO8)
/R1_DIO2: JP2.3 (B), U8.12 (DIO2), U9.12 (GPIO9)
/R1_DIO3: U8.6 (DIO3), U9.13 (GPIO10)
/R1_NSS: U8.19 (NSS), U9.7 (GPIO5)
/R1_RFI_N: U6.3 (RFI_N), U8.22 (RFI_N)
/R1_RFI_P: U6.4 (RFI_P), U8.21 (RFI_P)
/R1_RFO: L5.2, U6.1 (RFO), U8.23 (RFO)
/R1_RST: U8.15 (~NRESET), U9.14 (GPIO11)
/R1_SCK: U8.18 (SCK), U9.8 (GPIO6)
/R1_XTA: U8.3 (XTA), Y2.3
/R1_XTB: U8.4 (XTB), Y2.1
/RD+: R8.2, U9.47 (USB_DP)
/RD-: R10.2, U9.46 (USB_DM)
/RESET: RESET1.1, U9.26 (RUN)
/RXD: J3.3, U9.3 (GPIO1)
/SCL: J3.4, R9.2, U9.32 (GPIO21), U10.1 (SCL/SPC), U11.4 (SCK)
/SDA: J3.5, R15.2, U9.31 (GPIO20), U10.2 (SDA/SDI), U11.3 (SDI)
/SWCLK: J4.3, U9.24 (SWCLK)
/SWDIO: J4.2, U9.25 (SWD)
/TXD: J3.2, U9.2 (GPIO0)
GND: BOOT1.2, Button1.2, Button2.2, C1.2, C3.2, C4.2, C5.2, C6.1, C7.1, C8.2, C9.2, C10.2, C11.2, C12.2, C13.2, C14.2, C16.2, C17.2, C18.2, C19.2, C20.2, C21.2, C22.2, C23.2, C24.2, C25.2, C26.2, C27.2, C28.2, C29.2, C30.2, C31.2, C32.2, C33.2, C34.2, C35.2, C36.2, C37.2, C38.2, D2.1 (VSS), J1.2 (Ext), J2.2 (Ext), J3.1, J4.1, P1.A1 (GND), P1.A12 (GND), P1.B1 (GND), P1.B12 (GND), P1.S1 (SHIELD), R1.1, R2.1, RESET1.2, U1.2 (GND), U2.2 (GND), U2.5 (GND), U2.7 (GND), U2.9 (GND), U2.10 (GND), U3.2 (GND), U4.2 (GND), U4.5 (GND), U4.8 (GND), U4.20 (GND), U4.25 (EXP), U5.4 (GND), U6.2 (GND), U6.5 (GND), U6.7 (GND), U6.9 (GND), U6.10 (GND), U7.2 (GND), U8.2 (GND), U8.5 (GND), U8.8 (GND), U8.20 (GND), U8.25 (EXP), U9.19 (TESTEN), U9.57 (GND), U10.9 (GND), U10.10 (GND), U10.11 (GND), U10.12 (GND), U10.13 (GND), U10.14 (GND), U11.1 (GND), U11.5 (SDO), U11.7 (GND), Y1.2, Y1.4, Y2.2, Y2.4, Y3.2, Y3.4
unnamed: C2.2, C4.1, L1.2
unnamed: C15.2, C17.1, L4.2
unnamed: C30.1, R13.1, Y3.3
unnamed: D2.2 (DIN), R14.1
unnamed: F1.1, P1.A4 (VBUS), P1.A9 (VBUS), P1.B4 (VBUS), P1.B9 (VBUS)
unnamed: C3.1, J1.1 (In), L1.1
unnamed: C16.1, J2.1 (In), L4.1
unnamed: JP1.2 (C), R4.2
unnamed: JP2.2 (C), R7.2
unnamed: P1.A5 (CC), R1.2
unnamed: P1.B5 (VCONN), R2.2
unnamed: U2.6 (SW_RFI), U3.3 (RF2)
unnamed: U2.8 (SW_RFO), U3.1 (RF1)
unnamed: C2.1, U3.5 (RFC)
unnamed: C10.1, R3.1, U3.6 (V1)
unnamed: C12.1, R4.1, U3.4 (V2)
unnamed: L3.1, U4.9 (DCC_SW)
unnamed: C11.1, L3.2, U4.7 (VREG)
unnamed: C8.1, C9.1, L2.1, U4.24 (VR_PA)
unnamed: U6.6 (SW_RFI), U7.3 (RF2)
unnamed: U6.8 (SW_RFO), U7.1 (RF1)
unnamed: C15.1, U7.5 (RFC)
unnamed: C21.1, R6.1, U7.6 (V1)
unnamed: C23.1, R7.1, U7.4 (V2)
unnamed: L6.1, U8.9 (DCC_SW)
unnamed: C22.1, L6.2, U8.7 (VREG)
unnamed: C19.1, C20.1, L5.1, U8.24 (VR_PA)
unnamed: C29.1, U9.20 (XIN), Y3.1
unnamed: R13.2, U9.21 (XOUT)
VCC: C6.2, F1.2, U1.1 (VIN), U1.3 (EN)

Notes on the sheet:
Rx to ANT
I2C: 0x76
Condition
REGULATOR
SX1262
ANTENNA MATCHING/SWITCH LORA
RF1
RF2
FLASH
Tx to ANT
BUTTONS
MICROCONTROLLER
USB
SX1262
LEDS

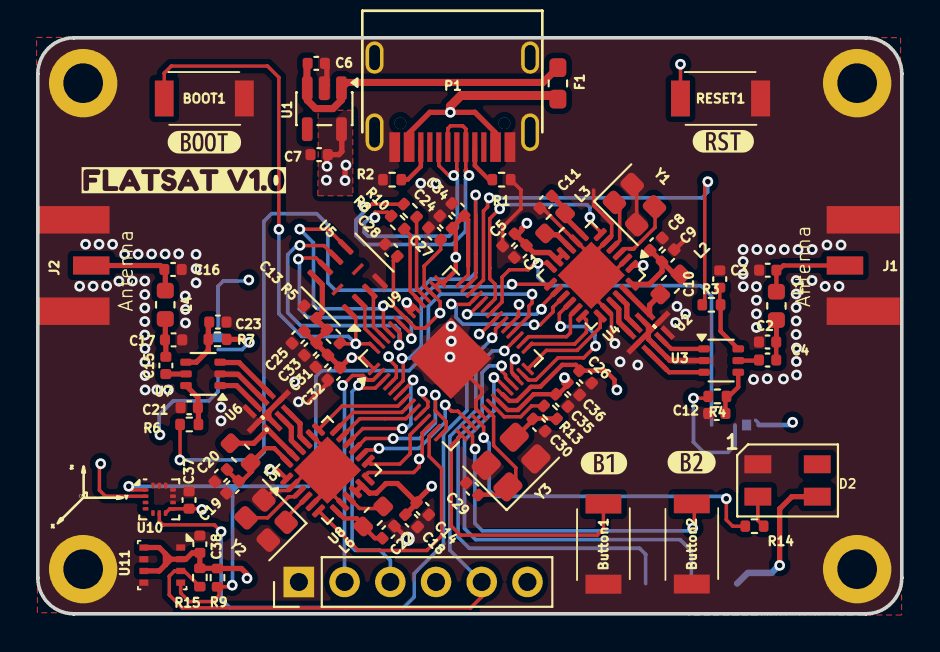
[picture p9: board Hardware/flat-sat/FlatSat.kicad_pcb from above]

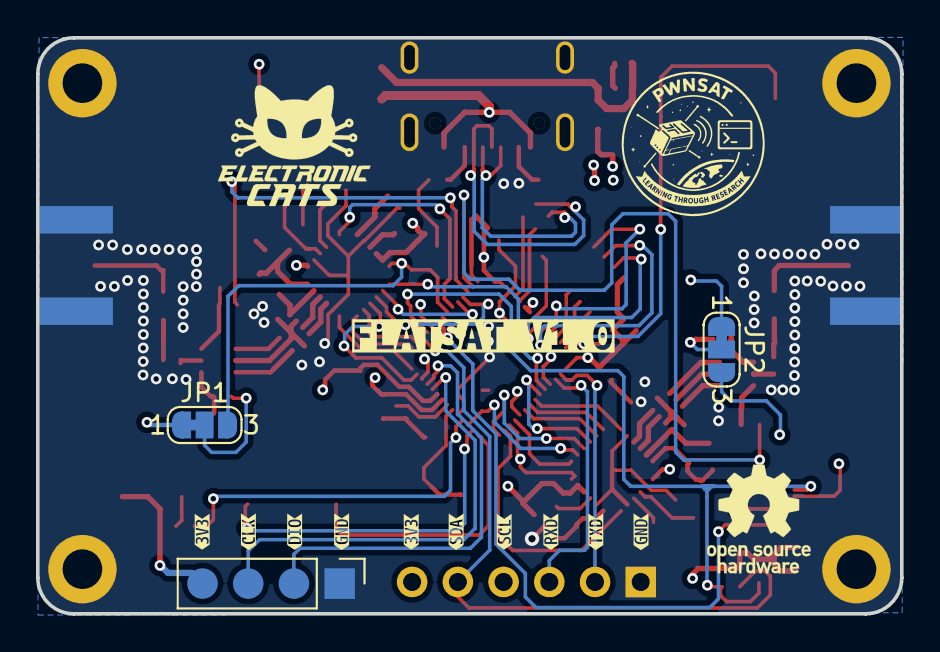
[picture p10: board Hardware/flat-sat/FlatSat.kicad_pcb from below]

Board: 4 copper layers, 48.0 x 32.0 mm, 100 parts (14 on the bottom side), 86 nets.

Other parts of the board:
kibuzzard-696512BA, kibuzzard-696512BA#2: G***; kibuzzard-696512BA
kibuzzard-696512FB: G***; kibuzzard-696512FB
kibuzzard-6965130C: G***; kibuzzard-6965130C
kibuzzard-6965136B: G***; kibuzzard-6965136B
kibuzzard-69651236: G***; kibuzzard-69651236
kibuzzard-69651254: G***; kibuzzard-69651254
kibuzzard-69651304: G***; kibuzzard-69651304
kibuzzard-69651319: G***; kibuzzard-69651319
kibuzzard-69651321: G***; kibuzzard-69651321
kibuzzard-69651375: G***; kibuzzard-69651375
kibuzzard-69651380: G***; kibuzzard-69651380
kibuzzard-69652909: G***; kibuzzard-69652909
kibuzzard-69652922: G***; kibuzzard-69652922
kibuzzard-69652959: G***; kibuzzard-69652959
kibuzzard-69653048: G***; kibuzzard-69653048

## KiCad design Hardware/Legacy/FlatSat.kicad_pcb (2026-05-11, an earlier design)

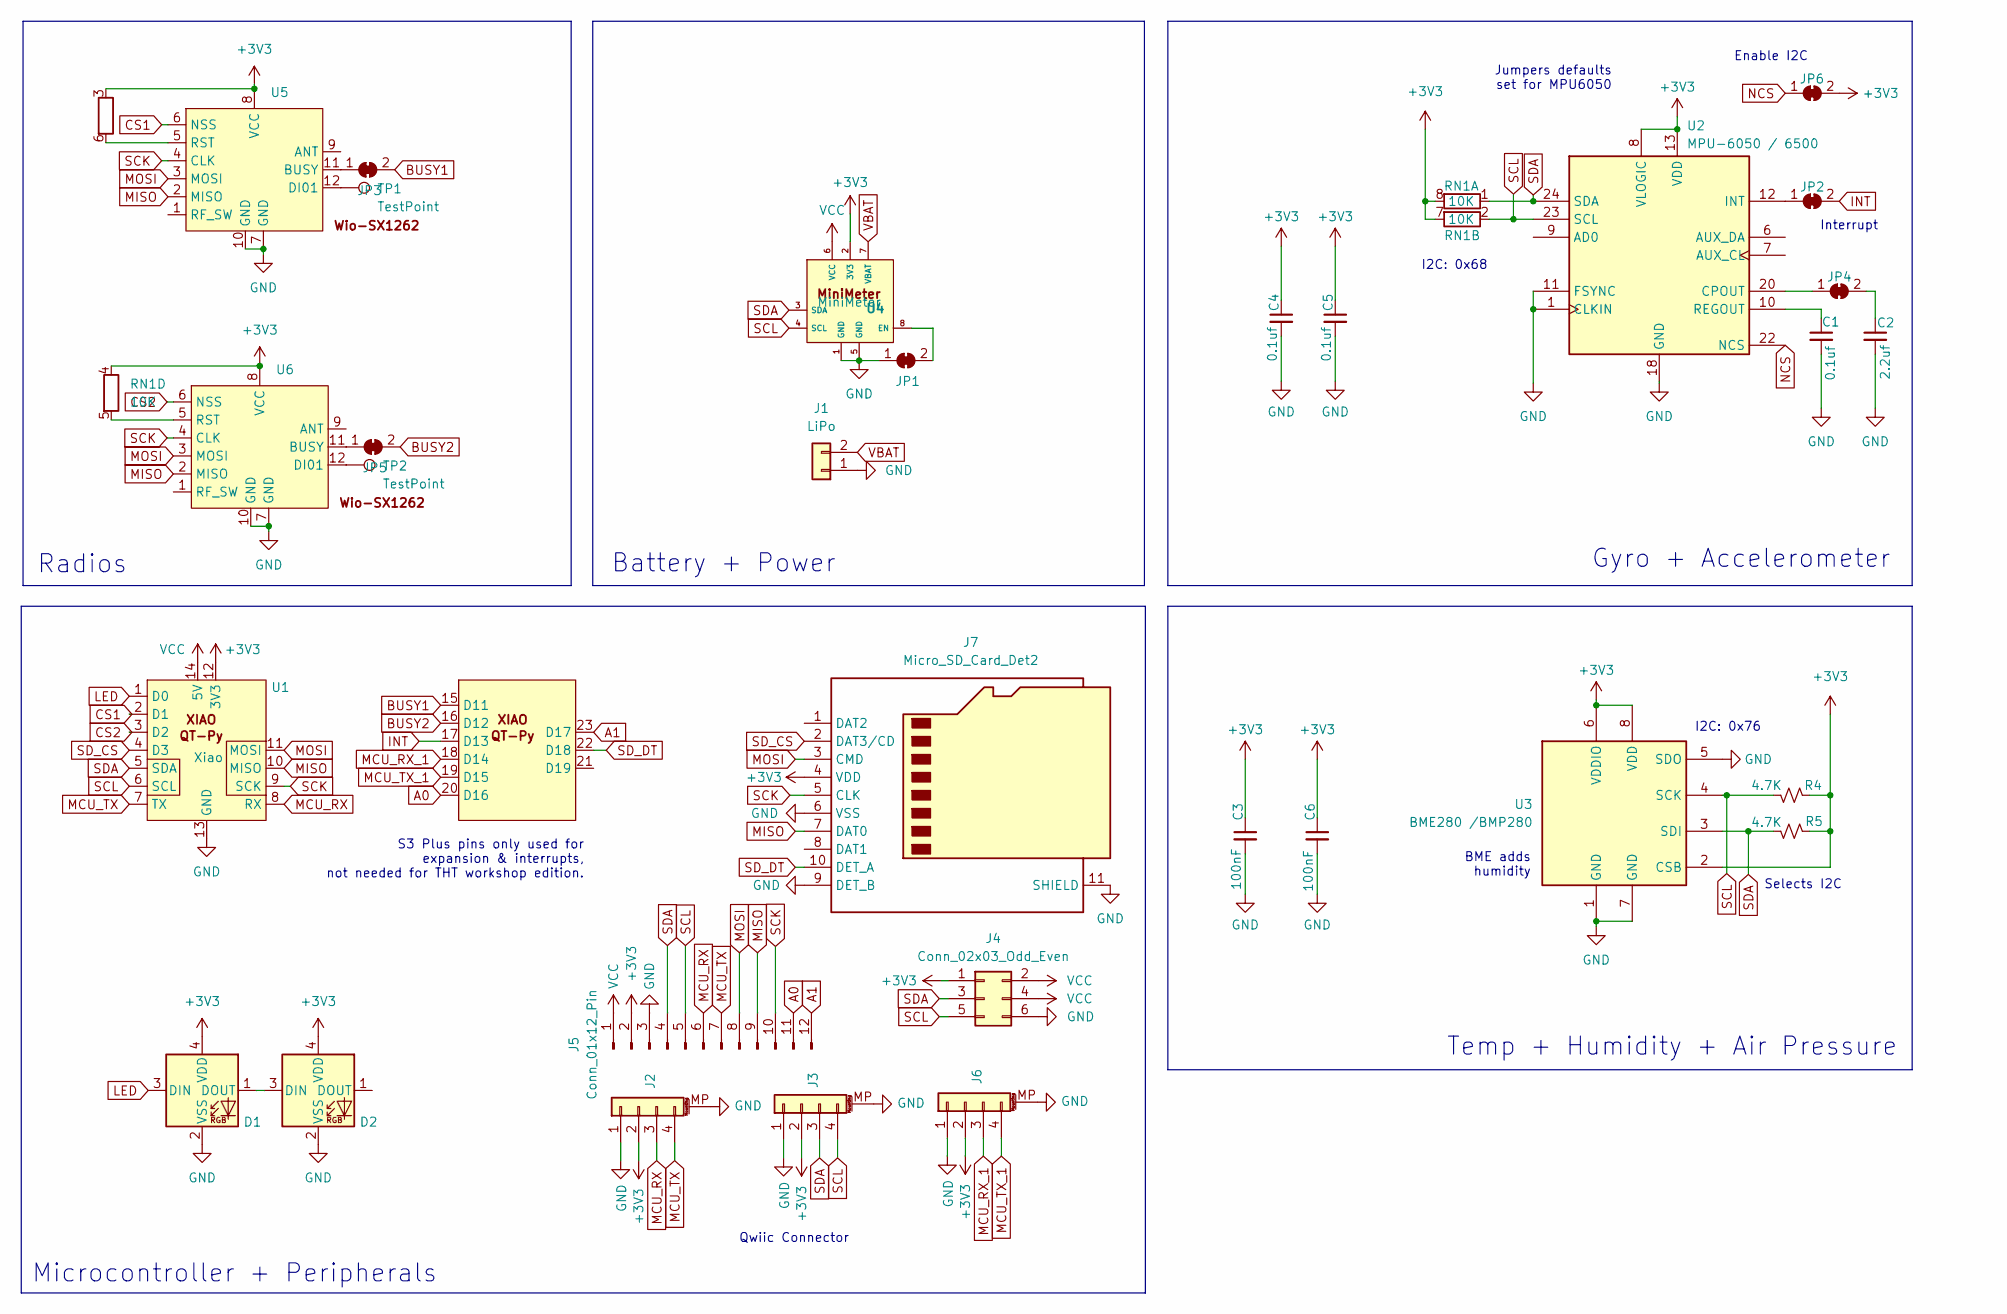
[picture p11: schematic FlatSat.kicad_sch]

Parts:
C1, C4, C5: 0.1uf; C_0603_1608Metric_Pad1.08x0.95mm_HandSolder
C2: 2.2uf; C_0603_1608Metric_Pad1.08x0.95mm_HandSolder
C3, C6: 100nF; C_0603_1608Metric_Pad1.08x0.95mm_HandSolder
D1, D2: SK6812MINI; LED_SK6812MINI_PLCC4_3.5x3.5mm_P1.75mm
J1: LiPo
J2, J3, J6: Conn_01x04_MountingPin
J4: Conn_02x03_Odd_Even
J5: Conn_01x12_Pin
J7: Micro_SD_Card_Det2
JP1, JP2, JP3, JP4, JP5, JP6: SolderJumper_2_Bridged; SolderJumper-2_P1.3mm_Bridged_RoundedPad1.0x1.5mm
R4, R5: 4.7K; R_0603_1608Metric
RN1: 10K; R_Array_Convex_4x0603
TP1: TestPoint; SolderJumper-2_P1.3mm_Open_RoundedPad1.0x1.5mm
TP2: TestPoint
U1: Xiao; XIAO-Generic
U2: MPU-6050 / 6500; InvenSense_QFN-24_4x4mm_P0.5mm
U3: BME280 /BMP280; Bosch_LGA-8_2.5x2.5mm_P0.65mm_ClockwisePinNumbering
U4: MiniMeter
U5, U6: (no value)

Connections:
+3V3: C3.1, C4.1, C5.1, C6.1, D1.4 (VDD), D2.4 (VDD), J2.2, J3.2, J4.1, J5.2, J7.4 (VDD), JP6.2 (B), R4.2, R5.1, RN1.3 (R3.1), RN1.4 (R4.1), RN1.7 (R2.2), RN1.8 (R1.2), U1.12 (3V3), U2.8 (VLOGIC), U2.13 (VDD), U3.2 (CSB), U3.6 (VDDIO), U3.8 (VDD), U4.2 (3V3), U5.8 (VCC), U6.8 (VCC)
A0: J5.11, U1.20 (D16)
A1: J5.12, U1.23 (D17)
BUSY1: JP3.2 (B), U1.15 (D11)
BUSY2: JP5.2 (B), U1.16 (D12)
CS1: U1.2 (D1), U5.6 (NSS)
CS2: U1.3 (D2), U6.6 (NSS)
GND: C1.2, C2.2, C3.2, C4.2, C5.2, C6.2, D1.2 (VSS), D2.2 (VSS), J1.1, J2.1, J2.MP (MountPin), J3.1, J3.MP (MountPin), J4.6, J5.3, J7.6 (VSS), J7.9 (DET_B), J7.11 (SHIELD), JP1.1 (A), U1.13 (GND), U2.1 (CLKIN), U2.11 (FSYNC), U2.18 (GND), U3.1 (GND), U3.5 (SDO), U3.7 (GND), U4.1 (GND), U4.5 (GND), U5.7 (GND), U5.10 (GND), U6.7 (GND), U6.10 (GND); also elsewhere on the board
INT: JP2.2 (B), U1.17 (D13)
LED: D1.3 (DIN), U1.1 (D0)
MCU_RX: J2.3, J5.6, U1.8 (RX)
MCU_RX_1: J6.3, U1.18 (D14)
MCU_TX: J2.4, J5.7, U1.7 (TX)
MCU_TX_1: J6.4, U1.19 (D15)
MISO: J5.9, J7.7 (DAT0), U1.10 (MISO), U5.2 (MISO), U6.2 (MISO)
MOSI: J5.8, J7.3 (CMD), U1.11 (MOSI), U5.3 (MOSI), U6.3 (MOSI)
NCS: JP6.1 (A), U2.22 (NCS)
unnamed: D1.1 (DOUT), D2.3 (DIN)
unnamed: JP1.2 (B), U4.8 (EN)
unnamed: JP2.1 (A), U2.12 (INT)
unnamed: JP3.1 (A), U5.11 (BUSY)
unnamed: JP4.1 (A), U2.20 (CPOUT)
unnamed: C2.1, JP4.2 (B)
unnamed: JP5.1 (A), U6.11 (BUSY)
unnamed: RN1.6 (R3.2), U5.5 (RST)
unnamed: RN1.5 (R4.2), U6.5 (RST)
unnamed: C1.1, U2.10 (REGOUT)
unnamed: TP1.1, U5.12 (DI01)
unnamed: TP2.1, U6.12 (DI01)
SCK: J5.10, J7.5 (CLK), U1.9 (SCK), U5.4 (CLK), U6.4 (CLK)
SCL: J3.4, J4.5, J5.5, R4.1, RN1.2 (R2.1), U1.6 (SCL), U2.23 (SCL), U3.4 (SCK), U4.4 (SCL)
SDA: J3.3, J4.3, J5.4, R5.2, RN1.1 (R1.1), U1.5 (SDA), U2.24 (SDA), U3.3 (SDI), U4.3 (SDA)
SD_CS: J7.2 (DAT3/CD), U1.4 (D3)
SD_DT: J7.10 (DET_A), U1.22 (D18)
VBAT: J1.2, U4.7 (VBAT)
VCC: J4.2, J4.4, J5.1, U1.14 (5V), U4.6 (VCC)

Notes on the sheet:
Radios
Jumpers defaults set for MPU6050
Microcontroller + Peripherals
BME adds humidity
I2C: 0x76
Gyro + Accelerometer
I2C: 0x68
Temp + Humidity + Air Pressure
Selects I2C
Interrupt
Battery + Power
Enable I2C
Qwiic Connector
S3 Plus pins only used for expansion & interrupts, not needed for THT workshop edition.

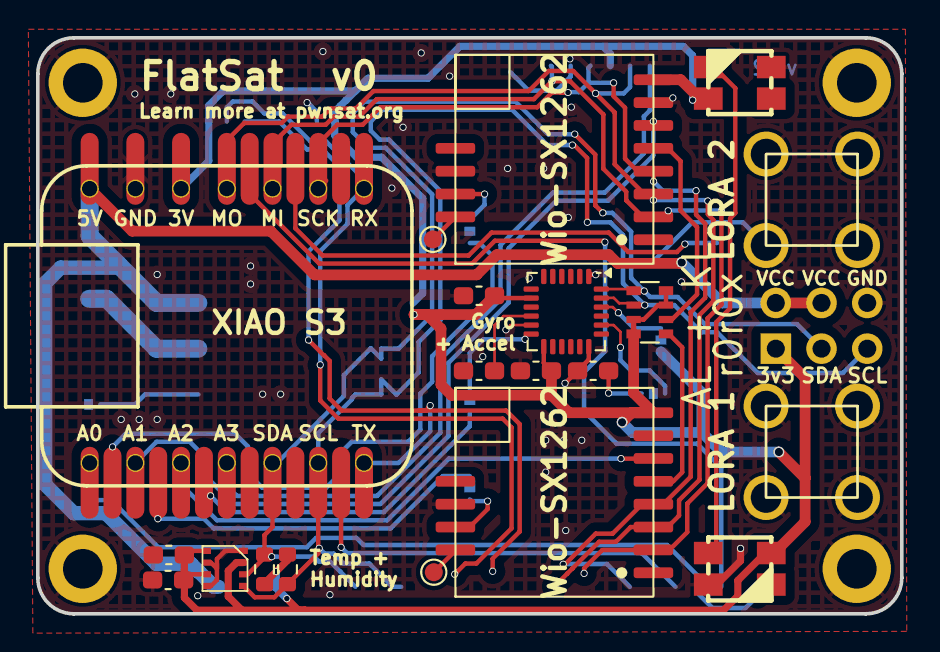
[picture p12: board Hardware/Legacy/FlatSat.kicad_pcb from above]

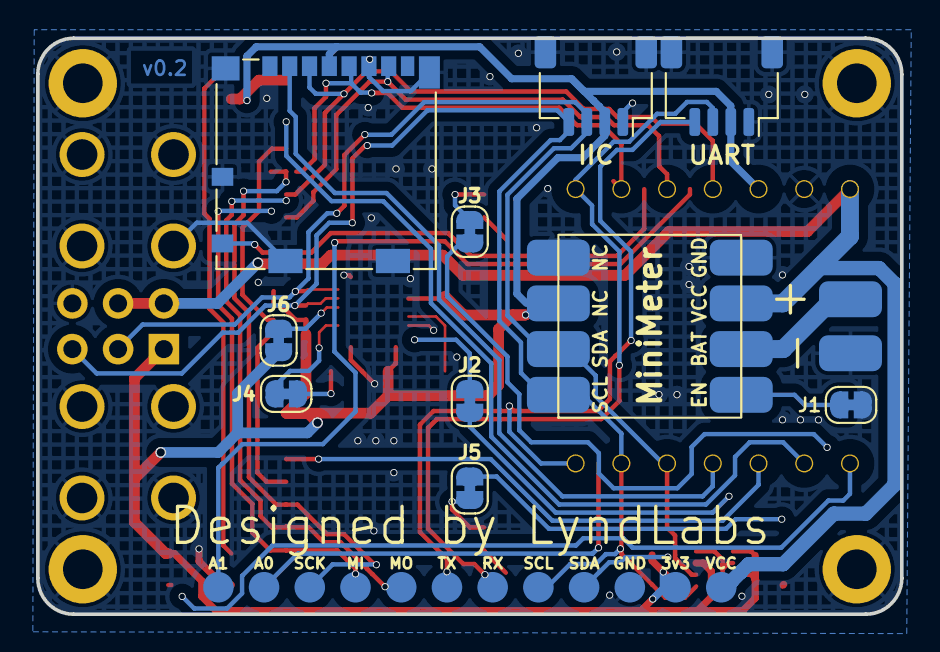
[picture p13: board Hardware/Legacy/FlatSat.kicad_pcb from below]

Board: 2 copper layers, 48.0 x 32.0 mm, 33 parts (12 on the bottom side), 34 nets.

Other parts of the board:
AE1, AE2: u.fl to SMA Edge Mount; SMA_Amphenol_901-143_Horizontal

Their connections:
GND: AE1.1, AE2.1; also elsewhere on the board

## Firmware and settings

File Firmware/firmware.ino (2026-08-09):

/*  - main.ino
 *
 * firmware - By astrobyte 18/03/26.
 *
 * SPDX-License-Identifier: GPL-2.0-or-later
 *
 */
#include "led.h"
#include "rdownlink.h"
#include "ruplink.h"
#include "sensors.h"
#include "spacecan.h"
#include "usbCDC.h"
#include "worker.h"

typedef struct {
  const unsigned long inverval;
  unsigned long previous;
} timeout_worker_t_t;

static timeout_worker_t_t t_tra = {.inverval = 5000, .previous = 0};

void setup() {
  obcSetupUSB();
  ledConfigure();
  obcConfigureCore0();
  sensorsConfigure();
  uplinkRadioConfigure();
  downlinkRadioConfigure();
  uplinkRadioRegisterCb(commandHandlerRadio);
  obcUSBPacketRecivedCallback(commandHandlerUSB);
  ledTurnWhite();
  delay(500);
  ledTurnOff();
}

void setup1() { obcConfigureCore1(); }

void loop() {
  gpsPoll();
  uplinkRadioCheckPacketReceived();
  downlinkRadioCheckTransmition();
  telemetryRadioWorker();
  if (consoleSensorModeActive()) {
    telemetryDashboardWorker();
  }
  consoleWorker();
}

void loop1() { obcUSBRecv(); }

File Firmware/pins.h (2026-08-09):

/*  - pins.h
 *
 * firmware - By astrobyte 18/03/26.
 *
 * SPDX-License-Identifier: GPL-2.0-or-later
 *
 */
#ifndef FIRMWARE_PINS_H
#define FIRMWARE_PINS_H

#define PIN_RGB_LED 15
#define PIN_BUTTON1 12
#define PIN_BUTTON2 13

/* Radio 0 */
#define PIN_SPI_RADIO0_CIPO 16 // MISO
#define PIN_SPI_RADIO0_SCK 18
#define PIN_SPI_RADIO0_COPI 19 // MOSI

#define PIN_RADIO0_NSS 17
#define PIN_RADIO0_RST 27
#define PIN_RADIO0_BSY 26
#define PIN_RADIO0_DIO1 3
#define PIN_RADIO0_DIO2 24
#define PIN_RADIO0_DIO3 25
#define PIN_RADIO0_ANT_SW 28

/* Radio 1 */
#define PIN_SPI_RADIO1_CIPO 4
#define PIN_SPI_RADIO1_SCK 6
#define PIN_SPI_RADIO1_COPI 7

#define PIN_RADIO1_NSS 5
#define PIN_RADIO1_RST 11
#define PIN_RADIO1_BSY 14
#define PIN_RADIO1_DIO1 8
#define PIN_RADIO1_DIO2 9
#define PIN_RADIO1_DIO3 10
#define PIN_RADIO1_ANT_SW 29

/* I2C */
#define PIN_I2C_SDA 20
#define PIN_I2C_SCL 21

/* GPS UART */
#define PIN_GPS_TX 0
#define PIN_GPS_RX 1
#endif // FIRMWARE_PINS_H

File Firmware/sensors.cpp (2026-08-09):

/*  - sensors.cpp
 *
 * firmware - By astrobyte 18/03/26.
 *
 * SPDX-License-Identifier: GPL-2.0-or-later
 *
 */
#include "sensors.h"
#include "SparkFun_LIS2DH12.h"
#include "mission.h"
#include "pins.h"
#include <Adafruit_BME280.h>
#include <Adafruit_Sensor.h>
#include <Wire.h>
#include <string.h>

Adafruit_BME280 bme;
SPARKFUN_LIS2DH12 accel;

#define GPS_BAUD_RATE 9600
#define GPS_LINE_BUFFER_SIZE 128
#define GPS_DETECT_TIMEOUT_MS 3000
#define GPS_NMEA_TIMEOUT_MS 4000
#define GPS_FIX_TIMEOUT_MS 5000

typedef struct {
  bool bmeOk;
  bool accOk;
  gps_nav_t gps;
  char gpsLine[GPS_LINE_BUFFER_SIZE];
  size_t gpsLineLen;
  bool gpsNmeaLogged;
  bool gpsMissingLogged;
} sensor_context_t;

static sensor_context_t s_context;

static void gpsClearFix(void) {
  s_context.gps.hasFix = false;
  s_context.gps.latitudeE7 = 0;
  s_context.gps.longitudeE7 = 0;
  s_context.gps.altitudeCm = 0;
  s_context.gps.satellites = 0;
  s_context.gps.lastFixMs = 0;
}

static void gpsClearDateTime(void) {
  s_context.gps.hasDateTime = false;
  s_context.gps.utcHour = 0;
  s_context.gps.utcMinute = 0;
  s_context.gps.utcSecond = 0;
  s_context.gps.utcDay = 0;
  s_context.gps.utcMonth = 0;
  s_context.gps.utcYear = 0;
  s_context.gps.lastDateTimeMs = 0;
}

static void sensorsInitAcc(void) {
  if (!accel.begin()) {
    Serial.print("[ERROR] ACC_NOT_DETECTED\r\n");
    s_context.accOk = false;
    return;
  }
  Serial.print("[INFO] ACC OK\r\n");
}

static void sensorsInitBme(void) {
  if (!bme.begin(BME_ADDR)) {
    Serial.printf("[ERROR] BMP_NOT_DETECTED. ID: 0x%02X \r\n", bme.sensorID());
    s_context.bmeOk = false;
    return;
  }
  Serial.print("[INFO] BME OK\r\n");
}

static bool gpsParseTwoDigits(const char *value, uint8_t *parsed) {
  if (value == NULL || parsed == NULL || value[0] == '\0' || value[1] == '\0') {
    return false;
  }
  if (value[0] < '0' || value[0] > '9' || value[1] < '0' || value[1] > '9') {
    return false;
  }

  *parsed = (uint8_t)(((value[0] - '0') * 10) + (value[1] - '0'));
  return true;
}

static bool gpsParseScaledDegrees(const char *value, char hemisphere,
                                  int32_t *scaled) {
  if (value == NULL || scaled == NULL || value[0] == '\0') {
    return false;
  }

  const double raw = atof(value);
  const int32_t degrees = (int32_t)(raw / 100.0);
  const double minutes = raw - ((double)degrees * 100.0);
  double decimal = (double)degrees + (minutes / 60.0);

  if (hemisphere == 'S' || hemisphere == 'W') {
    decimal *= -1.0;
  }

  *scaled = (int32_t)(decimal * 10000000.0);
  return true;
}

static bool gpsParseUtcTime(const char *value, uint8_t *hour, uint8_t *minute,
                            uint8_t *second) {
  if (value == NULL || hour == NULL || minute == NULL || second == NULL ||
      strlen(value) < 6) {
    return false;
  }

  return gpsParseTwoDigits(&value[0], hour) &&
         gpsParseTwoDigits(&value[2], minute) &&
         gpsParseTwoDigits(&value[4], second);
}

static bool gpsParseUtcDate(const char *value, uint8_t *day, uint8_t *month,
                            uint16_t *year) {
  uint8_t year_short = 0;

  if (value == NULL || day == NULL || month == NULL || year == NULL ||
      strlen(value) < 6) {
    return false;
  }

  if (!gpsParseTwoDigits(&value[0], day) ||
      !gpsParseTwoDigits(&value[2], month) ||
      !gpsParseTwoDigits(&value[4], &year_short)) {
    return false;
  }

  *year = (uint16_t)(2000 + year_short);
  return true;
}

static size_t gpsSplitLine(char *line, char **fields, size_t max_fields) {
  size_t field_count = 0;
  char *saveptr = NULL;

  for (char *token = strtok_r(line, ",", &saveptr);
       token != NULL && field_count < max_fields;
       token = strtok_r(NULL, ",", &saveptr)) {
    char *checksum = strchr(token, '*');
    if (checksum != NULL) {
      *checksum = '\0';
    }
    fields[field_count++] = token;
  }

  return field_count;
}

static void gpsRefreshAvailability(void) {
  const unsigned long now = millis();

  const bool raw_connected =
      s_context.gps.lastByteMs != 0 &&
      (now - s_context.gps.lastByteMs) <= GPS_NMEA_TIMEOUT_MS;
  const bool nmea_active =
      s_context.gps.lastNmeaMs != 0 &&
      (now - s_context.gps.lastNmeaMs) <= GPS_NMEA_TIMEOUT_MS;

  s_context.gps.connected = raw_connected;
  s_context.gps.nmeaActive = nmea_active;

  if (nmea_active) {
    if (!s_context.gpsNmeaLogged) {
      Serial.println("[INFO] GPS detected, valid NMEA stream active");
      s_context.gpsNmeaLogged = true;
      s_context.gpsMissingLogged = false;
    }
    return;
  }

  if (!raw_connected && now > GPS_DETECT_TIMEOUT_MS && !s_context.gpsMissingLogged) {
    Serial.println("[WARN] GPS not detected on UART, using zero-coordinate fallback");
    s_context.gpsMissingLogged = true;
    s_context.gpsNmeaLogged = false;
  } else if (raw_connected && s_context.gps.lastNmeaMs != 0 &&
             !s_context.gpsMissingLogged) {
    Serial.println("[WARN] GPS NMEA stream timed out, using zero-coordinate fallback");
    s_context.gpsMissingLogged = true;
    s_context.gpsNmeaLogged = false;
  }
}

static void gpsRegisterNmeaSentence(void) {
  s_context.gps.lastNmeaMs = millis();
  s_context.gps.nmeaActive = true;
}

static void gpsApplyGga(char *line) {
  char *fields[16] = {0};
  const size_t field_count = gpsSplitLine(line, fields, 16);

  if (field_count < 10) {
    return;
  }

  gpsRegisterNmeaSentence();

  const int fix_quality = atoi(fields[6]);
  const uint8_t satellites = (uint8_t)atoi(fields[7]);
  const unsigned long now = millis();

  if (fix_quality <= 0) {
    gpsClearFix();
    return;
  }

  int32_t latitude_e7 = 0;
  int32_t longitude_e7 = 0;
  if (!gpsParseScaledDegrees(fields[2], fields[3][0], &latitude_e7) ||
      !gpsParseScaledDegrees(fields[4], fields[5][0], &longitude_e7)) {
    gpsClearFix();
    return;
  }

  s_context.gps.hasFix = true;
  s_context.gps.latitudeE7 = latitude_e7;
  s_context.gps.longitudeE7 = longitude_e7;
  s_context.gps.altitudeCm = (int32_t)(atof(fields[9]) * 100.0);
  s_context.gps.satellites = satellites;
  s_context.gps.lastFixMs = now;
}
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

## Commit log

2025-03-28 initial schem
    [FlatSat-A.kicad_pcb, FlatSat-A.kicad_sch]
2025-03-29 add inital PCB design
    [FlatSat-A.kicad_pcb, FlatSat-A.kicad_sch, PCB-Outline.dxf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]
2025-04-14 push v0
    [FlatSat-A.kicad_pcb, FlatSat-A.kicad_sch, FlatSat.kicad_pcb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]
2025-04-14 add v0.0
    [FlatSat-B_Cu.gbr, FlatSat-B_Mask.gbr, FlatSat-B_Paste.gbr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]
2025-06-04 push v0.1 - MPU6500 compat & production files
    [FlatSat-B_Cu.gbr, FlatSat-B_Mask.gbr, FlatSat-B_Paste.gbr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]
2025-07-03 push FlatSat enclosure
    [FlatSat.kicad_pcb, v0-FlatSat-Enclosure.FCStd, v0-FlatSat-Enclosure.step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]
2026-04-06 feat(Hw):Update_Bom
    #part memory flash updated
    [FlatSat.csv, FlatSat.kicad_sch]
2026-05-11 chore: Update legacy version
    [FlatSat.kicad_pcb, FlatSat.kicad_sch, v0-FlatSat-Enclosure-Body_STL.stl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]
2026-08-09 Add Firmware/ and Attacks/, rename Hw/ to Hardware/
    Firmware/: the vulnerable-by-design firmware source (a superset of the
    public v1.0.0 baseline -- ground-station auth, mission modes, downlink
    encryption, simulated SpaceCAN bus, GPS nav), a pre-built .uf2, and
    platformio.ini to build it. See Firmware/README.md for the full diff.
    Attacks/: 8 attack scripts (00-07) exploiting the vulnerabilities above,
    each with an RF variant (HackRF/RTL-SDR) and a USB variant, plus the
    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
    [FlatSat.csv, FlatSat.kicad_pcb, FlatSat.kicad_sch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]
